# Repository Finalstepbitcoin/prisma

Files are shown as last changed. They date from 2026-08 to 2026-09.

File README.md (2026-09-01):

# Prisma — calcolatore offline

Un piccolo dispositivo **offline** che fa due cose sole:

1. **completa un seed BIP39** — gli dai le prime 11 (o 23) parole, lui calcola l'ultima
2. **costruisce una passphrase col metodo Diceware** — tu tiri i dadi, lui traduce i numeri in parole

Costa circa **20 euro** di componenti (aggiornato al 19 agosto 2026, a cui va aggiunto il case), non ha WiFi né Bluetooth, non salva niente
e il firmware è ispezionabile e riscrivibile da chiunque.

Canale YouTube: [Final Step Bitcoin](https://www.youtube.com/@final_step_bitcoin)

---

## Hai montato i pezzi. E adesso?

**Scarica un file solo e trascinalo.** Non serve installare niente sul
computer: ne' Python, ne' librerie, ne' le liste di parole.

1. prendi il file **`prisma-<versione>.uf2`** dall'ultima
   [release](https://github.com/Finalstepbitcoin/prisma/releases/latest);
2. tieni premuto **BOOTSEL** mentre colleghi il cavo micro-USB: compare un
   disco chiamato **RP2350**;
3. **trascina** il file su quel disco.

Il dispositivo riparte da solo e all'accensione mostra tre parole: devono
essere quelle scritte nella release.

**Se non ti fidi di quel file**, non usarlo: [costruiscitelo](#come-si-costruisce)
dal sorgente e verifica che venga identico, byte per byte. E' fatto apposta
perche' venga sempre lo stesso.

---

## Cosa serve

| Pezzo | Codice | Prezzo |
|---|---|---|
| Raspberry Pi Pico 2 con header | `RPI-PICO2-H` | ~7 € |
| Waveshare Pico-LCD-1.3 (240×240, joystick + 4 tasti) | `WS-19650` | ~9 € |
| Cavo micro-USB **dati** | `RPI-MUSB-1` | ~1,80 € |

**Attenzione a non prendere la versione "W"** del Pico: quella ha WiFi e Bluetooth,
e vanifica tutto il senso del progetto.

I due pezzi si incastrano. Il display va montato allineando il
simbolo USB stampato sul suo circuito con il connettore USB del Pico.

---

## Perché è fatto così

**Nessuna radio a bordo.** L'RP2350 non ha WiFi né Bluetooth: non è una scelta
del firmware, è il silicio che non li ha. È la garanzia più solida possibile.

**Non scrive nulla nella memoria permanente.** Le parole restano solo nella
memoria di lavoro e spariscono togliendo corrente. Questa scelta ha una
conseguenza importante: la memoria del dispositivo è **deterministica**, quindi
si può leggere e confrontare con quella di chiunque altro.

**Non genera entropia, la conserva.** Il caso lo porti tu — coi dadi, con una
moneta, come preferisci. Il dispositivo fa solo la traduzione, la stessa che
faresti a mano con le liste stampate, senza sbagliare riga.

**Non calcola chiavi private.** Niente derivazione, niente PBKDF2: il dispositivo
non può risalire al tuo portafoglio nemmeno per sbaglio.

**Il secure boot è deliberatamente disattivato.** Attivarlo impedirebbe
all'acquirente di riscrivere il firmware, cioè la garanzia più forte che questo
progetto possa offrire. È un pregio, non una mancanza.

---

## Come si costruisce

Serve Python 3 sul Mac o sul PC. Gli script usano solo la libreria standard,
tranne i due che impacchettano il file unico e disegnano il QR: quelli
vogliono una libreria ciascuno, installata in un ambiente isolato e con
l'impronta verificata (vedi `LEGGIMI-uf2.md`).

**Prima di tutto, MicroPython.** Non sta in questo repository, ed e' una
scelta: va preso dalla fonte, non dalle mani di chi ti vende il dispositivo.
Scarica da [micropython.org](https://micropython.org/download/RPI_PICO2/) la
versione per **Raspberry Pi Pico 2** e mettila nella cartella `firmware/`.

Quella usata qui e' `RPI_PICO2-20260406-v1.28.0.uf2`, SHA-256
`e65ad62a…b6ae`. Non e' un consiglio: gli script **rifiutano** qualunque
altro file, anche un `.uf2` di MicroPython legittimo ma di un'altra
versione. E' il motivo per cui due persone diverse, partendo dallo stesso
sorgente, ottengono un file finale **identico byte per byte**.

```bash
# 1. scarica dizionario e liste dalle fonti ufficiali, e disegna il QR
python3 prepara_wordlist.py
python3 prepara_diceware.py
.venv-strumenti/bin/python prepara_qr.py     # solo se cambia l'indirizzo

# 2. verifica che i calcoli siano corretti, PRIMA di toccare il dispositivo
python3 test_bip39.py
python3 test_diceware.py

# 3. impacchetta tutto in un file solo
.venv-strumenti/bin/python crea_uf2.py       # produce prisma-<versione>.uf2
.venv-strumenti/bin/python prova_uf2.py      # 12 controlli, senza dispositivo

# 4. annota le tre parole da pubblicare e stampare
python3 prepara_impronta.py
```

**Le liste di parole si scaricano dalle fonti originali** al momento della
compilazione, e ognuna resta sotto la propria licenza. In `liste-originali/`
c'e' anche una copia archiviata delle due liste Diceware, usata **solo** se il
download non riesce: serve a poter ricostruire il firmware anche se un domani
il sito di un autore non ci fosse piu', ed e' cio' che permette a chi riceve
un dispositivo gia' pronto di avere il sorgente corrispondente, come chiede la
licenza GPL della lista italiana. In tutti e due i casi gli script verificano
che la lista sia completa e ne confrontano l'impronta SHA-256 con quella
scritta nel codice: la copia archiviata e' una rete di sicurezza, non una
scorciatoia.

---

## Come si carica sul dispositivo

**Un file solo, e niente da installare sul computer.**

1. tieni premuto **BOOTSEL** mentre colleghi il cavo;
2. rilascia: compare un disco chiamato **RP2350**;
3. **trascina** `prisma-<versione>.uf2` su quel disco.

Il dispositivo si riavvia da solo dopo un paio di secondi e il disco
sparisce. Se il sistema avvisa che il disco non e' stato espulso
correttamente, e' normale: vuol dire che ha funzionato. All'accensione
devono comparire le tre parole dell'impronta.

**Su macOS il file va trascinato dal Finder, non copiato da terminale.**
`cp` scrive i settori in un ordine che il caricatore del Pico non accetta:
il file passa, il comando non da' errore, ma il dispositivo resta fermo in
BOOTSEL senza riavviarsi.

Dentro quel file c'e' **MicroPython intatto**, gli stessi byte che
distribuisce micropython.org, piu' un archivio con i file del programma.
Non e' una versione modificata: `prova_uf2.py` rilegge il file appena
prodotto e lo dimostra, blocco per blocco, prima che tu lo carichi.

### La strada lunga, per chi sviluppa

Chi lavora al codice e vuole cambiare un file alla volta senza rifare il
pacchetto ogni volta puo' ancora caricare MicroPython per conto suo e poi
copiare i file col terminale:

```bash
python3 installa.py     # copia tutti i file sul dispositivo in un colpo solo
```

Serve solo a questo. Per usare il dispositivo, o per darlo a qualcuno, la
strada e' il file unico qui sopra.

---

## I file

**Girano sul dispositivo**

| File | Cosa fa |
|---|---|
| `main.py` | tre righe: fa partire tutto all'accensione |
| `interfaccia.py` | menu, inserimento delle parole, schermate |
| `bip39_checksum.py` | il calcolo del checksum BIP39 |
| `impronta.py` | le tre parole mostrate all'accensione |
| `diceware.py` | dai numeri dei dadi alle parole |
| `schermo.py` | driver del display e lettura dei comandi |

**Girano sul computer**

| File | Cosa fa |
|---|---|
| `prepara_wordlist.py` | scarica e verifica il dizionario BIP39 |
| `prepara_diceware.py` | scarica e verifica le due liste Diceware |
| `test_bip39.py` | confronta i calcoli coi vettori ufficiali BIP39 |
| `test_diceware.py` | riconfronta le liste con le fonti, voce per voce |
| `prepara_qr.py` | disegna il QR del canale (unico script con una dipendenza) |
| `prepara_impronta.py` | calcola l'impronta attesa, da pubblicare e stampare |
| `crea_uf2.py` | impacchetta MicroPython e il programma in **un file solo** |
| `prova_uf2.py` | rilegge quel file e controlla che dentro ci sia il giusto |
| `installa.py` | la strada lunga: copia i file uno a uno, serve solo a chi sviluppa |
| `parla_col_pico.py` | parla col dispositivo senza installare programmi |
| `prova_percorsi.py` | ripercorre da solo tutte le strade dell'interfaccia |

---

## Come si verifica

I test scaricano i **vettori ufficiali BIP39** e controllano che il motore dia
esattamente i risultati previsti dallo standard — non "sembra funzionare", ma
*è dimostrato conforme*.

```
python3 test_bip39.py      →  186 controlli
python3 test_diceware.py   →   32 controlli
```

E sul dispositivo, una prova che ripercorre da sola ogni schermata e ogni
strada dell'interfaccia — inserimento parole, bit, dadi, ritorni indietro,
avvisi — controllando che nessuna finisca in errore:

```
python3 parla_col_pico.py copia prova_percorsi.py
python3 parla_col_pico.py esegui --pulito "import prova_percorsi"
                           →  18 percorsi
```

**Ricordati di togliere `prova_percorsi.py` dal dispositivo quando hai
finito**: e' un file in piu', quindi cambia l'impronta.

Fra questi ci sono due verifiche che vale la pena citare:

- la versione veloce del calcolo viene confrontata con una versione lenta e
  ovvia, tenuta nel codice apposta come metro di paragone
- per **tutte e 128** le posizioni possibili si verifica che i bit di entropia
  forniti dall'utente finiscano nella parola giusta

## L'impronta del firmware

All'accensione il dispositivo mostra **tre parole BIP39**. Sono i primi 33 bit
dello SHA-256 di tutto quello che esegue: la memoria del firmware piu' il
contenuto di **ogni file presente nel dispositivo** — tutti, non solo i `.py`,
comprese le sottocartelle. MicroPython infatti sa caricare anche i moduli gia'
compilati (`.mpy`) e cerca in `/lib`: misurare i soli `.py` avrebbe lasciato
uno spazio dove nascondere qualcosa.

```
python3 prepara_impronta.py
```

calcola lo stesso valore sul computer. Se le tre parole coincidono, dentro il
dispositivo c'e' esattamente quello che c'e' in questo repository.

Basta aggiungere un file perche' cambino — di qualunque tipo, anche dentro
una sottocartella: e' proprio quello che devono fare.

**Attenzione a cosa dimostra, e cosa NON dimostra**: e' il firmware stesso a
calcolare e mostrare queste tre parole. Un firmware malevolo mostrerebbe
comunque le parole giuste — sia che la manomissione sia avvenuta durante la
costruzione, sia durante il trasporto, in magazzino o presso un rivenditore:
in tutti questi casi chi manomette il dispositivo controlla lo stesso codice
che calcola l'impronta, e puo' farla tornare giusta a piacere.

Questo controllo serve solo contro il deterioramento accidentale della
memoria (un bit corrotto, un file mancante), **non contro una manomissione
voluta, di nessun tipo**. Per una prova vera serve leggere il contenuto da
SPENTI, con un canale che il firmware non controlla:

- `picotool save -a` / `picotool verify` da BOOTSEL, che risponde il
  bootloader in ROM col firmware fermo — vedi la guida
- oppure riscrivere tu stesso il firmware: invece di controllare quello che
  c'e' dentro, lo sostituisci con quello che scarichi tu

  **Attenzione al modo in cui si riscrive.** Il `.uf2` di MicroPython occupa
  i primi 320 KB della memoria, e il caricatore scrive SOLO i blocchi
  contenuti nel file: tutto quello che sta piu' in alto — compreso l'archivio
  dove vivono i dieci `.py` del programma — resta dov'era. Riscrivere
  MicroPython da solo quindi NON cancella i file gia' presenti. Per
  sostituire davvero tutto, la memoria va azzerata prima (`flash_nuke.uf2`
  di Raspberry Pi, oppure `picotool erase`).

---

## Comandi

| | |
|---|---|
| joystick | si muove fra lettere, voci di menu, elenchi |
| A | conferma, scegli |
| B | cancella, torna indietro |
| X e Y | i valori 1 e 0 quando si inseriscono i bit |

Nei tiri di dado: su = 1, destra = 2, giù = 3, sinistra = 4, centro = 5,
tasto X = 6. Lo schema è disegnato sullo schermo.

---

## Avvertenze

**Spegnere significa staccare il cavo, non premere RESET.** Il reset riavvia il
processore ma non azzera la memoria di lavoro.

**Una passphrase non ha checksum.** Se la trascrivi male non te ne accorgi: non
compare nessun errore, entri semplicemente in un altro portafoglio, vuoto. Il
seed BIP39 invece da questo ti protegge.

**Alimentalo da un caricatore da telefono**, non dal computer. Molte power bank
si spengono da sole quando l'assorbimento è basso come quello di questo
dispositivo.

**Questo progetto non è stato sottoposto ad audit professionali.** I calcoli sono
verificati contro i vettori ufficiali, il resto è codice scritto con cura ma non
revisionato da terzi. Trattalo di conseguenza.

---

## Licenze

Il codice di questo progetto è sotto licenza **MIT** (vedi `LICENSE`).

Le liste di parole restano di chi le ha fatte, ognuna con la propria licenza,
e sono archiviate in [`liste-originali/`](liste-originali/) insieme al testo
della GPL. Il firmware assemblato, contenendo la lista Diceware italiana, esce
sotto **GPL-3.0**. I dettagli sono in [`LICENZE-TERZI.md`](LICENZE-TERZI.md).

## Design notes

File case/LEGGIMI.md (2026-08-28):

# Custodia da stampare in 3D

**→ <https://makerworld.com/en/models/3230142-raspberry-pi-pico-2-case-waveshare-1-3-lcd>**

## Di chi è, e cosa puoi farci

| | |
|---|---|
| Disegno | **Zez0000** su MakerWorld |
| Basato su | il modello originale di **Tomáš Plass** ([Printables](https://www.printables.com/model/1322102-waveshare-pico-13-lcd-case)) |
| Licenza | **Creative Commons Attribuzione - Non commerciale (CC BY-NC)** |

Attenzione, la licenza della custodia **non è quella di Prisma**. Il firmware e tutto il resto del repository sono MIT, quindi liberi anche per usi commerciali; la custodia no: **CC BY-NC vuol dire che puoi stamparla per te, ma non venderla né vendere un dispositivo che la monta.** Se ti serve per qualcosa di commerciale, devi chiedere il permesso a chi l'ha disegnata.

## Come si stampa

Le impostazioni consigliate da chi l'ha disegnata:

- materiale **PLA**
- altezza strato **0,20 mm**
- **2 pareti**, riempimento **15%**
- circa **40 minuti** in tutto

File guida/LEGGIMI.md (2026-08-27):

# Guida d'uso — "Prisma, guida pratica"

Questa guida spiega l'utilizzo del dispositivo: come si accende, come si usano
le due modalità, come si verifica il firmware, cosa non bisogna fare. Viene
consegnata a chi acquista "Prisma" già assemblato.

## Il PDF

`PRISMA - GUIDA PRATICA.pdf` è il foglio pronto da stampare, fronte/retro
su un A4. È la stessa identica copia che finisce nella scatola: `build.sh`
la aggiorna qui in automatico ogni volta che rigenera il foglio, così le due
non possono divergere.

### Attenzione alle tre parole stampate sopra

Sulla prima facciata, nel riquadro arancione, ci sono **tre parole BIP39**:
sono l'impronta del firmware caricato sui dispositivi assemblati. Un
Prisma già montato deve mostrare esattamente quelle all'accensione.

**Se il firmware lo compili tu**, quelle tre parole non ti dicono niente sul
tuo dispositivo: calcola le tue con `python3 prepara_impronta.py` e confronta
con quelle che vedi sullo schermo. È il confronto che conta, non il valore
stampato qui.

A ogni cambio di firmware vengono aggiornate tutte e due le copie della
guida — quella di carta nella scatola e questo PDF — così le tre parole
restano quelle vere.

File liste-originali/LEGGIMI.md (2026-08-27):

# Le liste originali, archiviate qui

In questa cartella ci sono le **liste di parole Diceware così come sono state
scaricate** dalle pagine dei loro autori, senza nessuna modifica: sono i file
da cui `prepara_diceware.py` genera `diceware_en.py` e `diceware_it.py`, cioè
quello che poi finisce dentro il dispositivo.

## Perché stanno qui

Due motivi, tutti e due pratici.

**Perché il firmware sia ricostruibile anche fra dieci anni.** Se un giorno il
sito di un autore non c'è più, senza queste copie non sarebbe più possibile
rigenerare il firmware né controllare che quello installato corrisponda al
sorgente. La verifica del dispositivo si regge tutta su questa possibilità.

**Perché la licenza lo chiede.** Il firmware assemblato contiene la lista
italiana, che è GPL-3.0. Chi riceve un dispositivo già pronto deve poter
ottenere il sorgente corrispondente: adesso è qui, insieme al codice.

Attenzione, le copie **non sostituiscono la verifica**: `prepara_diceware.py`
scarica sempre dalla fonte originale e usa questi file solo se il download non
riesce. In tutti e due i casi confronta lo SHA-256 con quello scritto nel
codice, e si ferma se non corrisponde. La copia archiviata è una rete di
sicurezza, non una scorciatoia.

## Cosa c'è

### `diceware-inglese-reinhold.asc`

| | |
|---|---|
| Autore | Arnold Reinhold, che il metodo Diceware l'ha inventato nel 1995 |
| Licenza | **CC-BY 4.0** — uso commerciale permesso, serve l'attribuzione |
| Pagina | <https://theworld.com/~reinhold/diceware.html> |
| File | <https://theworld.com/~reinhold/diceware.wordlist.asc> |
| SHA-256 | `3cd6164a99e95381f8620aec782a933545bcd5833fa331d267a6829f6665256e` |
| Voci | 7776 |

Reinhold concede la lista inglese sotto CC-BY 4.0. Il *testo della sua pagina*
è invece CC-BY-NC-ND, cioè non commerciale: è una distinzione da non
confondere, qui si usa la lista.

### `diceware-italiana-gamberini-v4.txt`

| | |
|---|---|
| Autore | Tarin Gamberini |
| Licenza | **GPL-3.0-or-later** (testo completo in `COPYING-GPL-3.0.txt`) |
| Pagina | <https://www.taringamberini.com/it/diceware_it_IT/lista-di-parole-diceware-in-italiano/> |
| File | versione 4, `word_list_diceware_it-IT-4.txt` |
| SHA-256 | `b441559b64fb7041b9bbcecb3c43111f2523ec84e172670409f40c462eda0b93` |
| Voci | 7776 |

Non è la traduzione di quella inglese: è una lista a sé, e lo stesso tiro di
dadi dà una parola diversa nelle due liste.

### `COPYING-GPL-3.0.txt`

Il testo completo della licenza GPL-3.0, scaricato da
<https://www.gnu.org/licenses/gpl-3.0.txt>. Vale per la lista italiana e per
il firmware che la contiene.

## Cosa NON cambia

Il codice di questo progetto resta sotto licenza **MIT** (vedi `LICENSE`).
I file di questa cartella non sono nostri e restano di chi li ha fatti, ognuno
con la propria licenza. Il firmware assemblato, contenendo la lista italiana,
esce sotto **GPL-3.0**: è scritto in `LICENZE-TERZI.md`.

Il dizionario BIP39 inglese non sta qui: fa parte della specifica pubblica di
Bitcoin e si scarica dal repository ufficiale dei BIP, che non è il sito
personale di nessuno.

## Se una lista viene aggiornata dall'autore

Non basta sostituire il file. La procedura è:

1. scaricare la nuova versione e **guardarla**, confrontandola con la vecchia;
2. aggiornare `impronta_attesa` dentro `prepara_diceware.py`;
3. sostituire il file in questa cartella e aggiornare lo SHA-256 qui sopra;
4. rilanciare `prepara_diceware.py`, `test_diceware.py` e `crea_uf2.py`;
5. rifare la guida con `guida/build.sh`: cambiando la lista cambia il
   firmware, e quindi cambiano le tre parole dell'impronta stampate sul
   foglio. `build.sh` da solo si rifiuta di stampare se non le si aggiorna.

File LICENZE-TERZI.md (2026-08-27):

# Licenze e attribuzioni

Questo progetto usa liste di parole e idee di altre persone. Qui c'è scritto
di chi sono e a quali condizioni si possono usare.

Gli script `prepara_wordlist.py` e `prepara_diceware.py` scaricano le liste
dalle fonti originali al momento della compilazione. Delle due liste Diceware
c'è anche una **copia archiviata** in [`liste-originali/`](liste-originali/),
usata solo se il download non riesce: senza, il giorno in cui il sito di un
autore sparisse non sarebbe più possibile ricostruire il firmware né darne il
sorgente a chi ha comprato un dispositivo, come invece la GPL richiede.

Il codice di questo progetto resta sotto licenza MIT. I file archiviati non
sono nostri: ognuno resta sotto la licenza del proprio autore, indicata qui
sotto e ripetuta nel `LEGGIMI.md` di quella cartella.

---

## Dizionario BIP39 (inglese, 2048 parole)

- **Fonte**: [repository ufficiale dei BIP](https://github.com/bitcoin/bips/blob/master/bip-0039/english.txt)
- **Standard**: [BIP-39](https://github.com/bitcoin/bips/blob/master/bip-0039.mediawiki)
- Fa parte della specifica pubblica di Bitcoin.

## Lista Diceware inglese (7776 voci)

- **Autore**: Arnold Reinhold, che il metodo Diceware l'ha inventato nel 1995
- **Licenza**: **CC-BY 4.0** — uso commerciale permesso, serve l'attribuzione
- **Pagina**: <https://theworld.com/~reinhold/diceware.html>
- **Copia archiviata**: `liste-originali/diceware-inglese-reinhold.asc`

Sulla sua pagina Reinhold scrive che concede i diritti sulla lista inglese
sotto CC-BY 4.0. Attenzione a non confondersi: il *testo della pagina* è invece
CC-BY-NC-ND, cioè non commerciale. È la lista che ci interessa, ed è quella
permissiva.

## Lista Diceware italiana (7776 voci)

- **Autore**: Tarin Gamberini
- **Licenza**: **GPL-3.0-or-later** per la versione testuale (testo completo
  della licenza in `liste-originali/COPYING-GPL-3.0.txt`)
- **Pagina**: <https://www.taringamberini.com/it/diceware_it_IT/lista-di-parole-diceware-in-italiano/>
- **Copia archiviata**: `liste-originali/diceware-italiana-gamberini-v4.txt`

Non è la traduzione di quella inglese: è una lista a sé, e lo stesso numero di
dadi dà una parola diversa nelle due liste.

## Motore dei calcoli

La logica del checksum BIP39 deriva da **[embit](https://github.com/diybitcoinhardware/embit)**
(licenza MIT), una libreria Bitcoin pensata per i sistemi embedded. È la stessa
libreria usata sia da [SeedSigner](https://github.com/SeedSigner/seedsigner) sia
da [Krux](https://github.com/selfcustody/krux).

I vettori di test provengono da
**[trezor/python-mnemonic](https://github.com/trezor/python-mnemonic)**, l'implementazione
di riferimento dello standard.

## MicroPython

Il dispositivo esegue [MicroPython](https://micropython.org/) (licenza MIT).

---

## Le due librerie usate per costruire

Non finiscono dentro il dispositivo: servono sul computer, al momento di
preparare i file. Le citiamo lo stesso, perche' chi ricostruisce il progetto
le scarica.

- **littlefs-python** (BSD-3-Clause), di Jurg Rast — impacchetta i file del
  programma nell'archivio del `.uf2`. E' un involucro attorno alla libreria C
  littlefs, la stessa che gira dentro MicroPython.
  <https://github.com/jrast/littlefs-python>
- **segno** (BSD-3-Clause) — disegna i codici QR stampati sulla guida.
  <https://github.com/heuer/segno>

## Cosa significa in pratica

**Il codice di questo repository è MIT**: chiunque può prenderlo e farne quello
che vuole, anche a scopo commerciale, mantenendo l'avviso di copyright.

**Un firmware assemblato che includa la lista italiana esce sotto GPL-3.0**,
perché quella lista è GPL. In pratica questo obbliga chi lo distribuisce a
fornire i sorgenti e a permettere all'acquirente di installare una versione
modificata — cioè esattamente quello che questo progetto promette comunque.

Un firmware con la sola lista inglese non ha questo vincolo: MIT e CC-BY
bastano.

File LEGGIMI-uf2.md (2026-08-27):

# Il file unico — note di lavoro

Serve a produrre **un solo file** da trascinare sul dispositivo, al posto
di "carica MicroPython, poi copia dieci file col terminale".

Nato sul ramo `uf2-unico`, portato qui il 27 agosto 2026 dopo la prima
prova su hardware vero.

## Cosa c'è di nuovo

| File | Cosa fa |
|---|---|
| `crea_uf2.py` | costruisce `prisma-<versione>.uf2` |
| `prova_uf2.py` | rilegge il file prodotto e controlla che dentro ci sia il giusto |

Non è stata toccata **nessuna riga** del programma che gira sul dispositivo:
cambia solo il modo in cui i file ci arrivano dentro.

## Come si usa

```bash
.venv-strumenti/bin/python crea_uf2.py     # produce prisma-1.0.uf2
.venv-strumenti/bin/python prova_uf2.py    # 12 controlli, senza dispositivo
```

## La libreria in più

`crea_uf2.py` è l'unico pezzo del progetto che ha bisogno di
**littlefs-python** (BSD-3-Clause, involucro attorno alla libreria C
littlefs 2.11.2 — la stessa che gira dentro MicroPython sul dispositivo).

Va installata **solo nell'ambiente isolato**, mai nel Python di sistema, e
sempre verificando l'impronta del pacchetto. I comandi qui sotto sono per
**Mac con chip Apple**: su un altro sistema cambia il nome del pacchetto, e
con esso l'impronta da confrontare — quella giusta si prende dalla pagina
del progetto su PyPI.

```bash
python3 -m venv .venv-strumenti
curl -o littlefs_python-0.19.0-cp314-cp314-macosx_11_0_arm64.whl \
  https://files.pythonhosted.org/packages/26/12/ab923553e4894fbf44f4692d6c5898c1e66f41e57ff7a73b90e8aa0fb6f5/littlefs_python-0.19.0-cp314-cp314-macosx_11_0_arm64.whl
shasum -a 256 littlefs_python-0.19.0-cp314-cp314-macosx_11_0_arm64.whl
#  deve dare: d054ac280541afdae5722fb8d7ebc0e121d822c33d95d57889fd8fab2a211486
.venv-strumenti/bin/pip install --no-index --no-deps littlefs_python-*.whl
```

Non serve né a chi compra il dispositivo né a chi vuole solo verificare i
calcoli: quelli restano due comandi con la sola libreria standard di Python.

## I parametri dell'archivio: da dove vengono

Non sono stati indovinati. Vengono dalla sorgente ufficiale di MicroPython e
devono combaciare **esattamente**, altrimenti il dispositivo si accende e non
trova niente:

| Valore | Da dove | Quanto |
|---|---|---|
| dimensione archivio | `ports/rp2/boards/RPI_PICO2/mpconfigboard.cmake` | 3.145.728 byte (3 MB) |
| inizio archivio | `ports/rp2/rp2_flash.c` (4 MB − 3 MB) | 1 MB, cioè `0x10100000` |
| blocco | `ports/rp2/rp2_flash.c`, `FLASH_SECTOR_SIZE` | 4096 byte |
| scrittura | `ports/rp2/modules/_boot.py`, `VfsLfs2(bdev, progsize=256)` | 256 byte |

Il firmware finisce a 320 KB, l'archivio comincia a 1024 KB: in mezzo restano
i dati di collaudo che il Raspberry Pi scrive in fabbrica a 508 KB, che non
vengono né scritti né misurati.

## Due cose che è importante sapere

**L'immagine è sempre identica a parità di file.** Ricostruita tre volte di
fila dà lo stesso SHA-256: chiunque può rifare il file e ottenere il nostro,
byte per byte. Senza questa proprietà l'intera storia della verifica non
starebbe in piedi.

**Le tre parole dell'impronta non cambiano.** L'impronta misura MicroPython
(che resta intatto) e i dieci file (che sono gli stessi): un dispositivo
caricato col file unico è indistinguibile da uno installato col metodo
vecchio. `prova_uf2.py` lo verifica.

## Perché il file è da 1 MB e non da 6

littlefs sparge i file in giro per l'archivio invece di metterli in fila —
lo fa apposta, per non consumare sempre le stesse celle. Scrivendo tutto il
tratto dal primo all'ultimo blocco usato ci porteremmo dietro 2,4 MB di
vuoto. Siccome ogni blocco `.uf2` si porta dietro il proprio indirizzo, si
scrivono solo i blocchi che contengono qualcosa.

È sicuro anche rispetto a un'installazione precedente: il caricatore del Pico
cancella l'intero settore da 4096 byte prima di scriverne anche un pezzo, e
l'elenco dei file (i primi due blocchi) viene riscritto per intero, quindi
niente di vecchio resta raggiungibile.

## La prova sull'hardware: fatta il 27 agosto 2026

Caricato su un Pico 2 vero: il disco si smonta da solo, il dispositivo
riparte e mostra `Prisma 1.0` con le tre parole dell'impronta.

**La prima prova ha bocciato il file**, ed e' servita esattamente a questo.
Il dispositivo restava fermo in BOOTSEL: il file veniva scritto per intero,
nessun errore da nessuna parte, ma niente riavvio. Il motivo era la
numerazione dei blocchi, che il caricatore conta **per famiglia** e non su
tutto il file (il dettaglio sta nel commento dentro `crea_uf2.py`). I dodici
controlli passavano lo stesso, perche' due di essi pretendevano proprio la
regola sbagliata: sono stati riscritti.

Se un domani qualcosa non andasse, il sintomo dice dove guardare:

- **il disco resta montato e non riparte** → la numerazione dei blocchi
- **si accende ma resta muto** → i parametri dell'archivio non combaciano
- **riparte in modo continuo** → problema nel firmware, non nell'archivio
- **tre parole diverse da quelle attese** → nell'archivio e' finito qualcosa
  in piu' o in meno

**Su macOS il file va trascinato dal Finder**, non copiato da terminale:
`cp` scrive i settori in un ordine che il caricatore non accetta, non da'
errore, e il dispositivo resta fermo senza che nulla lo segnali.

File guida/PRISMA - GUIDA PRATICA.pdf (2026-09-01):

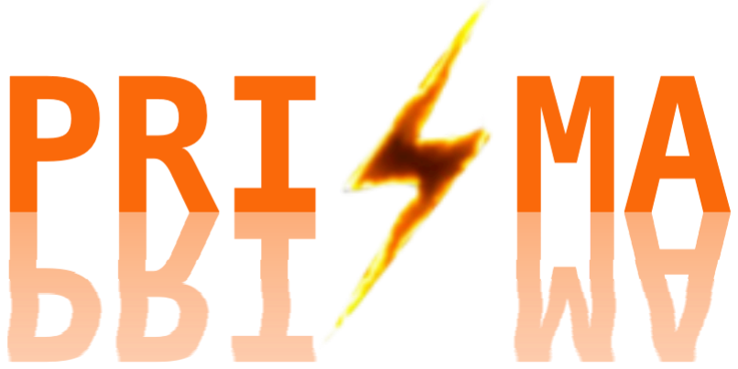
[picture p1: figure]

# GUIDA PRATICA

DISPOSITIVO OFFLINE · ULTIMA PAROLA BIP39 E PASSPHRASE DICEWARE

## 1 COSA FA E COSA NON FA

M O D A L I T À 1

### CHECKSUM

Gli dai le prime 11 parole del seed (o
le prime 23) e lui calcola l’ultima valida.

M O D A L I T À 2

### PASSPHRASE

Tu tiri i dadi, lui li traduce in parole della lista Diceware. Il caso lo porti tu.

Q U E L L O C H E N O N F A
Niente WiFi né Bluetooth: non è una scelta del programma, è il chip che non li ha. Non salva niente e non calcola chiavi private: non può risalire al tuo portafoglio.

## 2 ACCENDILO E CONTROLLA L’IMPRONTA

Collegalo con un cavo micro-USB a un caricatore da telefono, non al computer: molte power bank potrebbero non funzionare perché il dispositivo assorbe pochissimo. Per una maggiore sicurezza puoi aggiungere un Data Blocker USB. Non c’è niente da installare, parte da solo. Ma se non ti fidi, puoi scaricare il firmware da github.com/Finalstepbitcoin/prisma e installarlo in autonomia.

ALL’ACCENSIONE DEVE MOSTRARE
STABLE CHAIR PROBLEM

Sono l’impronta di tutto quello che il dispositivo esegue. Se ne mostra tre diverse, dentro c’è qualcosa di diverso: fermati e riscrivi il firmware.
Protegge solo da un guasto accidentale, non da una manomissione voluta: un firmware manomesso potrebbe mostrarle comunque giuste. Verifica vera al punto 6.

Confrontale con quelle pubblicate su Nostr da questa chiave: npub17ugguepv89nvdrd72j7j25ymuts6w3d3lnsg6f0xgm2ah8zskhqq3v5ulj

## 3 I COMANDI

joystick | si muove fra lettere, voci di menu ed elenchi | B | cancella; a casella vuota torna indietro
A | conferma, sceglie | X e Y | i valori 1 e 0 quando si inseriscono i bit

Nei tiri di
dado:
su = 1 | destra = 2 | giù = 3 | sinistra = 4 | centro = 5 | X = 6

— lo schema è disegnato sullo schermo.

## 4 MODALITÀ CHECKSUM: L’ULTIMA PAROLA DEL SEED

Un errore nell’inserimento delle parole darebbe un checksum corretto, ma su parole sbagliate. Il dispositivo ti mostrerà le parole che hai inserito. Controllale prima di proseguire. Una volta terminato, non fotografare lo schermo per salvare la parola.
1 Menu → Checksum. Scegli se il tuo seed è da 12 o da 24 parole.

2

Inserisci le prime 11 parole (o 23). Per ogni parola compare la griglia delle sole lettere ancora possibili: il joystick si muove, A conferma. Quando restano cinque parole o meno te le mostra e scegli quella giusta.
B cancella una lettera; a casella vuota, torna alla parola precedente.

3 Aspetta il calcolo. Con 11 parole ci mette circa 3 secondi e mezzo, con 23 circa 6: la barra arancione mostra a che punto

### 4 Scegli come completare. Il dispositivo propone tre strade:

Bit rimasti — quella giusta: inserisci i 7 bit che ti avanzano dai dadi (3 se il seed è da 24), nell’ordine in cui li hai generati. X vale 1,

Scegli tu — se non ti avanzano bit di entropia puoi sceglierne una a caso (NON consigliato): scorri l’elenco, X filtra per iniziale. Tutti zeri — butta via i bit che avanzano. Solo se sai perché lo stai facendo.

5 Copia la parola che compare grande, in verde, e rileggila confrontandola con lo schermo.
6 Stacca il cavo. L’ultima schermata è un vicolo cieco voluto: nessun tasto porta da nessuna parte. È l’unico modo di azzerare davvero la memoria di lavoro.

PRISMA · GUIDA PRATICA | FACCIATA 2 DI 2

## 5 MODALITÀ PASSPHRASE: I DADI E LA LISTA DICEWARE

1 Menu → Passphrase. Scegli la lista: Inglese (Reinhold) o Italiano (Gamberini). Sono 7.776 voci ciascuna e non sono la traduzione l’una dell’altra: sono due liste indipendenti.
2 Tira cinque dadi per ogni parola e registra i valori col joystick. Cinque dadi fanno 6×6×6×6×6 = 7.776 combinazioni: una per ogni voce, nessuno scarto.
Se un lancio non ti piace, tienilo lo stesso. Ritirarlo rimette la tua testa nel processo e distrugge la casualità.
3 Guarda i bit che stai accumulando. Dopo ogni parola: A per farne un’altra, Y per fermarti. Sotto le 6 parole il dispositivo ti avvisa ogni volta; il massimo è 20 (258,5 bit), in due schermate da dieci.
4 Se compare “copiala esatta!” la voce contiene simboli o cifre — per esempio a, @, i’ve, 12. Sono legittime e vanno copiate esattamente così.
5 Copia tutte e due le schermate finali — prima l’elenco numerato, poi la passphrase per intero — sullo stesso foglio. Poi stacca il cavo.
Con più di 10 parole l’elenco numerato sta su due schermate, con una freccia per passare alla seconda: copiale entrambe.

U N A P A S S P H R A S E N O N H A
C H E C K S U M
Se la trascrivi male non ricevi nessun
errore: entri semplicemente in un altro portafoglio, vuoto. Il seed BIP39 da questo ti protegge, la passphrase no.

C O M E S C R I V E R E L A
P A S S P H R A S E
rune a @ issue cat orin è la stringa da digitare, spazi compresi. Senza spazio, due parole potrebbero confondersi. Se vuoi scrivere la passphrase senza gli spazi, assicurati di conservare l’elenco delle parole.

C O M E S A L V A R E L A
P A S S P H R A S E
Viene mostrato sia l’elenco delle singole parole, sia la stringa intera, per una doppia conferma. Salvali entrambi. Annota anche come scriverai la passphrase (con/senza spazi). Non fotografare mai lo schermo.

## 6 COME VERIFICARE IL FIRMWARE

LIVELLO 1 Le tre parole all’accensione. Immediato, ma è il programma che parla di sé: rileva un guasto accidentale, non una manomissione voluta.

LIVELLO 2 Riscrivilo tu. È il percorso più sicuro: invece di controllare quello che c’è dentro, lo sostituisci con quello che scarichi tu. Inquadra il codice QR o vai su github.com/Finalstepbitcoin/prisma e segui le istruzioni.

LIVELLO 3 Leggilo e confrontalo. Sempre da BOOTSEL, un programma di verifica rilegge la memoria a dispositivo spento: risponde il bootloader di fabbrica, non il firmware. È l’unica verifica che il firmware non può falsificare.

CODICE GITHUB

## 7 AVVERTENZE

S P E G N E R E = S T A C C A R E I L
C A V O
Il tasto RESET riavvia il processore ma non azzera la memoria di lavoro. L’unico spegnimento vero è togliere la corrente.

U N A M O D A L I T À P E R S E S S I O N E
Usa checksum e passphrase in due sessioni separate, staccando il cavo in mezzo: così il dispositivo non ha mai in memoria tutte e due le metà del tuo segreto.

T R A S C R I V I I L R I S U L T A T O
Trascrivi il segreto (ultima parola o passphrase). Attenzione al foglio su cui scrivi perché contiene il tuo segreto in chiaro: conservalo o distruggilo dopo aver copiato i segreti su un supporto metallico.

Progetto libero e ispezionabile. Dizionario BIP39 dal repository ufficiale dei BIP · lista Diceware inglese di Arnold Reinhold (CC BY 4.0) · lista Diceware italiana di Tarin Gamberini (GPL-3.0-or-later) · motore dei calcoli derivato da embit (MIT), la stessa libreria usata da SeedSigner e Krux. Il codice del progetto è MIT; il firmware assemblato, contenendo la lista italiana, esce sotto GPL-3.0. Questo progetto non è stato sottoposto ad audit professionali: i calcoli sono verificati contro i vettori ufficiali BIP39, il resto è codice scritto con cura ma non revisionato da terzi. Trattalo di conseguenza.

FINAL STEP BITCOIN
YOUTUBE.COM/@FINAL_STEP_BITCOIN WWW.FINALSTEPBITCOIN.COM

Trovi anche una video guida sul mio canale YouTube

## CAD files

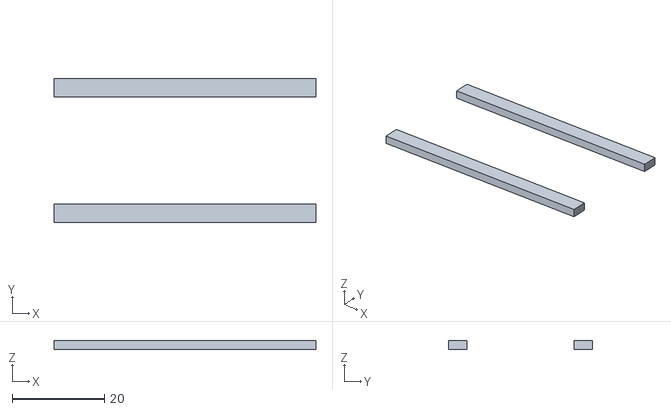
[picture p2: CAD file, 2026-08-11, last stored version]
case/cornice.stl
56.8 x 31.3 x 2.00

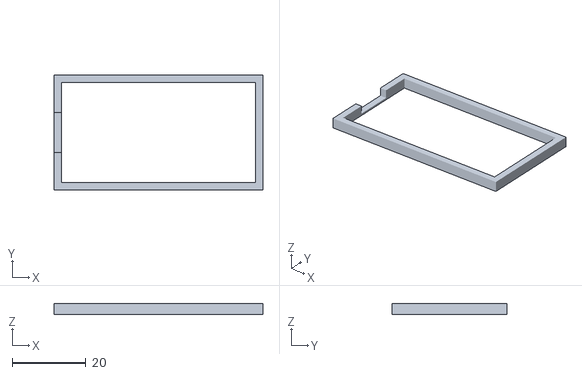
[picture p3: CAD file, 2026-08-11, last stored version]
case/prova_incastro.stl
56.8 x 31.3 x 3.00

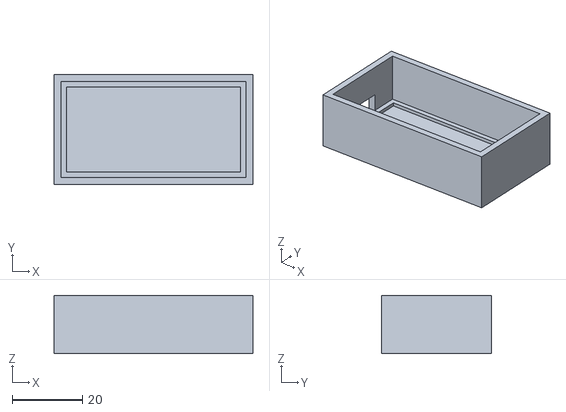
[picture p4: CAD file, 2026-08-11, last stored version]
case/vassoio.stl
56.8 x 31.3 x 16.6

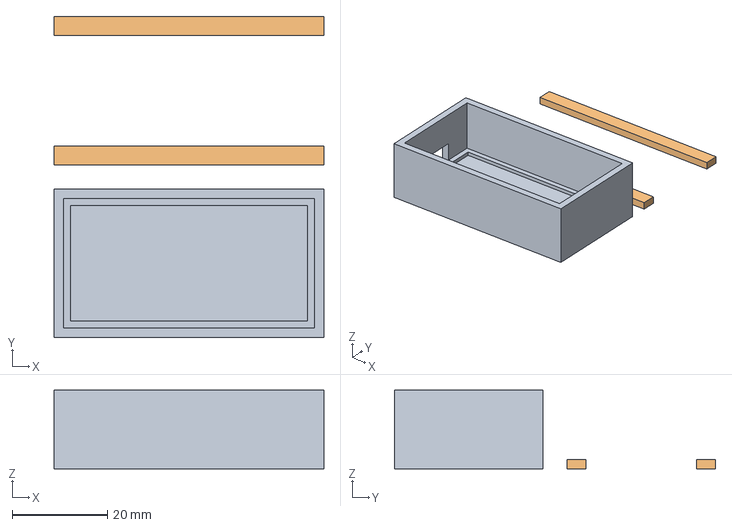
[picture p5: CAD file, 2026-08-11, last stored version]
case/custodia_completa.3mf
56.8 x 67.6 x 16.6 mm
vassoio
cornice

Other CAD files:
case/custodia_completa.stl

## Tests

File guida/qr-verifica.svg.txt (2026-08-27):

<svg class="qr" viewBox="-2 -2 33 33" xmlns="http://www.w3.org/2000/svg" shape-rendering="crispEdges"><rect x="-2" y="-2" width="33" height="33" fill="#fff"/><path fill="#000" d="M0 0h7v1h-7zM8 0h1v1h-1zM11 0h3v1h-3zM17 0h2v1h-2zM22 0h7v1h-7zM0 1h1v1h-1zM6 1h1v1h-1zM8 1h1v1h-1zM10 1h2v1h-2zM13 1h2v1h-2zM16 1h1v1h-1zM18 1h3v1h-3zM22 1h1v1h-1zM28 1h1v1h-1zM0 2h1v1h-1zM2 2h3v1h-3zM6 2h1v1h-1zM8 2h1v1h-1zM11 2h3v1h-3zM20 2h1v1h-1zM22 2h1v1h-1zM24 2h3v1h-3zM28 2h1v1h-1zM0 3h1v1h-1zM2 3h3v1h-3zM6 3h1v1h-1zM11 3h1v1h-1zM13 3h1v1h-1zM15 3h3v1h-3zM19 3h2v1h-2zM22 3h1v1h-1zM24 3h3v1h-3zM28 3h1v1h-1zM0 4h1v1h-1zM2 4h3v1h-3zM6 4h1v1h-1zM8 4h2v1h-2zM18 4h2v1h-2zM22 4h1v1h-1zM24 4h3v1h-3zM28 4h1v1h-1zM0 5h1v1h-1zM6 5h1v1h-1zM10 5h1v1h-1zM13 5h1v1h-1zM16 5h2v1h-2zM20 5h1v1h-1zM22 5h1v1h-1zM28 5h1v1h-1zM0 6h7v1h-7zM8 6h1v1h-1zM10 6h1v1h-1zM12 6h1v1h-1zM14 6h1v1h-1zM16 6h1v1h-1zM18 6h1v1h-1zM20 6h1v1h-1zM22 6h7v1h-7zM9 7h1v1h-1zM11 7h1v1h-1zM13 7h4v1h-4zM18 7h3v1h-3zM0 8h1v1h-1zM3 8h7v1h-7zM11 8h2v1h-2zM14 8h1v1h-1zM16 8h2v1h-2zM21 8h1v1h-1zM24 8h1v1h-1zM26 8h3v1h-3zM0 9h1v1h-1zM2 9h1v1h-1zM5 9h1v1h-1zM7 9h1v1h-1zM13 9h3v1h-3zM19 9h1v1h-1zM21 9h1v1h-1zM23 9h2v1h-2zM26 9h2v1h-2zM0 10h1v1h-1zM4 10h1v1h-1zM6 10h2v1h-2zM9 10h3v1h-3zM14 10h3v1h-3zM18 10h1v1h-1zM20 10h1v1h-1zM23 10h2v1h-2zM26 10h1v1h-1zM0 11h1v1h-1zM2 11h1v1h-1zM4 11h2v1h-2zM9 11h2v1h-2zM14 11h1v1h-1zM16 11h2v1h-2zM19 11h5v1h-5zM25 11h1v1h-1zM28 11h1v1h-1zM2 12h1v1h-1zM5 12h2v1h-2zM9 12h1v1h-1zM11 12h2v1h-2zM16 12h1v1h-1zM19 12h2v1h-2zM22 12h2v1h-2zM28 12h1v1h-1zM0 13h3v1h-3zM4 13h1v1h-1zM9 13h1v1h-1zM11 13h1v1h-1zM13 13h1v1h-1zM15 13h2v1h-2zM19 13h1v1h-1zM22 13h7v1h-7zM0 14h4v1h-4zM5 14h3v1h-3zM12 14h1v1h-1zM15 14h1v1h-1zM19 14h4v1h-4zM24 14h1v1h-1zM26 14h1v1h-1zM28 14h1v1h-1zM4 15h1v1h-1zM9 15h1v1h-1zM15 15h1v1h-1zM18 15h2v1h-2zM23 15h2v1h-2zM26 15h1v1h-1zM28 15h1v1h-1zM3 16h5v1h-5zM11 16h3v1h-3zM19 16h3v1h-3zM25 16h1v1h-1zM0 17h1v1h-1zM4 17h1v1h-1zM8 17h1v1h-1zM10 17h4v1h-4zM15 17h1v1h-1zM17 17h3v1h-3zM24 17h1v1h-1zM26 17h2v1h-2zM0 18h2v1h-2zM3 18h4v1h-4zM9 18h2v1h-2zM12 18h2v1h-2zM15 18h1v1h-1zM17 18h1v1h-1zM19 18h1v1h-1zM24 18h2v1h-2zM28 18h1v1h-1zM0 19h2v1h-2zM5 19h1v1h-1zM10 19h4v1h-4zM15 19h1v1h-1zM19 19h1v1h-1zM22 19h1v1h-1zM25 19h2v1h-2zM0 20h2v1h-2zM3 20h2v1h-2zM6 20h1v1h-1zM8 20h2v1h-2zM12 20h1v1h-1zM14 20h4v1h-4zM20 20h8v1h-8zM8 21h1v1h-1zM10 21h2v1h-2zM14 21h2v1h-2zM20 21h1v1h-1zM24 21h2v1h-2zM0 22h7v1h-7zM8 22h2v1h-2zM11 22h1v1h-1zM14 22h2v1h-2zM17 22h4v1h-4zM22 22h1v1h-1zM24 22h2v1h-2zM0 23h1v1h-1zM6 23h1v1h-1zM8 23h1v1h-1zM10 23h1v1h-1zM12 23h1v1h-1zM14 23h1v1h-1zM17 23h4v1h-4zM24 23h1v1h-1zM0 24h1v1h-1zM2 24h3v1h-3zM6 24h1v1h-1zM8 24h8v1h-8zM19 24h7v1h-7zM27 24h1v1h-1zM0 25h1v1h-1zM2 25h3v1h-3zM6 25h1v1h-1zM8 25h1v1h-1zM10 25h1v1h-1zM14 25h3v1h-3zM18 25h1v1h-1zM21 25h1v1h-1zM28 25h1v1h-1zM0 26h1v1h-1zM2 26h3v1h-3zM6 26h1v1h-1zM9 26h1v1h-1zM12 26h1v1h-1zM14 26h2v1h-2zM17 26h2v1h-2zM20 26h2v1h-2zM23 26h2v1h-2zM26 26h3v1h-3zM0 27h1v1h-1zM6 27h1v1h-1zM9 27h1v1h-1zM12 27h1v1h-1zM16 27h1v1h-1zM18 27h1v1h-1zM22 27h2v1h-2zM25 27h2v1h-2zM28 27h1v1h-1zM0 28h7v1h-7zM8 28h5v1h-5zM14 28h1v1h-1zM19 28h2v1h-2zM22 28h1v1h-1zM24 28h1v1h-1z"/></svg>

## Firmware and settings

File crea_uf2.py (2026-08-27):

#!/usr/bin/env python3
"""
crea_uf2.py  --  Final Step Bitcoin / Prisma

Costruisce UN SOLO file da trascinare sul dispositivo, che contiene sia
MicroPython sia il programma.

GIRA SUL MAC. Serve la libreria littlefs-python nell'ambiente isolato
.venv-strumenti (vedi LEGGIMI-uf2.md).

Uso:
    .venv-strumenti/bin/python crea_uf2.py

PERCHE' ESISTE
Fino a ieri chi voleva installarsi il software da solo doveva: azzerare la
memoria, caricare MicroPython, installare Python sul computer, aprire il
terminale e lanciare tre script che copiano dieci file uno per uno.
Con questo file: tiene premuto BOOTSEL, collega il cavo, trascina un file.
Trenta secondi, nessun programma da installare.

COME E' FATTO UN FILE .uf2
Non e' un formato misterioso: e' un elenco di blocchi da 512 byte, ognuno
dei quali dice "scrivi questi 256 byte a questo indirizzo". Il caricatore
del Pico li scrive uno per uno. Noi ne mettiamo insieme due gruppi:

    0x10000000  MicroPython           (320 KB, presi dal .uf2 ufficiale)
    0x10100000  l'archivio coi file   (costruito qui sul Mac)

I due gruppi non si toccano: il firmware finisce a 320 KB, l'archivio
comincia a 1024 KB. In mezzo, a 508 KB, ci sono i dati di collaudo che il
Raspberry Pi scrive in fabbrica: non li tocchiamo ne' li misuriamo (e' la
stessa ragione per cui l'impronta si ferma a 448 KB).

I PARAMETRI DELL'ARCHIVIO NON SONO INVENTATI
Vengono dalla sorgente di MicroPython, e devono combaciare ESATTAMENTE,
altrimenti il dispositivo si accende e non trova niente:

  ports/rp2/boards/RPI_PICO2/mpconfigboard.cmake
      MICROPY_HW_FLASH_STORAGE_BYTES 3145728        -> 3 MB di archivio
  ports/rp2/rp2_flash.c
      MICROPY_HW_FLASH_STORAGE_BASE (PICO_FLASH_SIZE_BYTES - STORAGE_BYTES)
                                                    -> comincia a 4MB-3MB = 1MB
      BLOCK_SIZE_BYTES (FLASH_SECTOR_SIZE)          -> blocchi da 4096 byte
  ports/rp2/modules/_boot.py
      vfs.VfsLfs2(bdev, progsize=256)               -> scritture da 256 byte
"""

import hashlib
import os
import re
import struct
import sys

# --- i valori presi dalla sorgente di MicroPython (vedi sopra) -------------
INIZIO_FLASH = 0x10000000
ARCHIVIO_INIZIO = 1024 * 1024          # 1 MB dall'inizio della memoria
ARCHIVIO_BYTE = 3145728                # 3 MB
BLOCCO = 4096
SCRITTURA = 256                        # progsize
LETTURA = 32                           # readsize, il valore predefinito

# --- il formato .uf2 -------------------------------------------------------
UF2_MAGIC0 = 0x0A324655
UF2_MAGIC1 = 0x9E5D5157
UF2_MAGIC_FINE = 0x0AB16F30
UF2_FLAG_FAMIGLIA = 0x00002000
CARICO = 256                           # byte utili per blocco

# --- cosa va dentro --------------------------------------------------------
# La stessa lista di installa.py e prepara_impronta.py.
FILE_DISPOSITIVO = (
    "bip39_checksum.py",
    "diceware.py",
    "diceware_en.py",
    "diceware_it.py",
    "impronta.py",
    "interfaccia.py",
    "main.py",
    "qr_canale.py",
    "schermo.py",
    "wordlist.py",
)

# La versione NON si scrive qui: si legge da interfaccia.py, che e' quella
# che il dispositivo mostra sullo schermo. Tenendone due copie, prima o poi
# il nome del file e la scritta sullo schermo direbbero numeri diversi.
VERSIONE = re.search(r'VERSIONE\s*=\s*"([^"]+)"',
                     open("interfaccia.py").read()).group(1)


# ---------------------------------------------------------------------------
# 1. l'archivio
# ---------------------------------------------------------------------------

def costruisci_archivio():
    """
    L'immagine dell'archivio, con dentro i dieci file.

    Nessuna data di modifica viene scritta: cosi' l'immagine e' sempre
    identica a parita' di file, e chiunque puo' rifarla e ottenere lo
    stesso identico risultato. E' la stessa ragione per cui il dispositivo
    non scrive niente da solo.
    """
    try:
        from littlefs import LittleFS
    except ImportError:
        # Senza questo messaggio si vedrebbe solo un errore di Python, e chi
        # non programma non saprebbe che gli manca una libreria, ne' quale.
        print("ERRORE: manca la libreria littlefs, che serve a impacchettare")
        print("i file del programma dentro il .uf2.")
        print()
        print("Si installa nell'ambiente isolato del progetto, verificandone")
        print("l'impronta: la procedura completa e' in LEGGIMI-uf2.md, sotto")
        print("\"La libreria in piu'\".")
        print()
        print("Non serve per verificare i calcoli: test_bip39.py e")
        print("test_diceware.py girano con la sola libreria standard.")
        sys.exit(1)

    fs = LittleFS(block_size=BLOCCO,
                  block_count=ARCHIVIO_BYTE // BLOCCO,
                  prog_size=SCRITTURA,
                  read_size=LETTURA,
                  mount=False)
    fs.format()
    fs.mount()
    for nome in FILE_DISPOSITIVO:
        with open(nome, "rb") as f:
            dati = f.read()
        with fs.open(nome, "wb") as f:
            f.write(dati)
        print("   %-20s %7d byte" % (nome, len(dati)))
    fs.unmount()
    return bytes(fs.context.buffer)


# ---------------------------------------------------------------------------
# 2. il file .uf2
# ---------------------------------------------------------------------------

def leggi_uf2(percorso):
    """I blocchi del .uf2 ufficiale di MicroPython: (indirizzo, dati, famiglia)."""
    with open(percorso, "rb") as f:
        dati = f.read()
    if len(dati) % 512:
        sys.exit("ERRORE: %s non e' un .uf2 valido." % percorso)
    fuori = []
    for i in range(len(dati) // 512):
        b = dati[i * 512:(i + 1) * 512]
        m0, m1, bandiere, indirizzo, quanti = struct.unpack("<5I", b[:20])
        famiglia = struct.unpack("<I", b[28:32])[0]
        if m0 != UF2_MAGIC0 or m1 != UF2_MAGIC1:
            continue
        # Le bandiere vanno CONSERVATE, non ricostruite. Il primo blocco dei
        # .uf2 per RP2350 ha anche il bit 0x8000 ("qui dentro ci sono tag di
        # estensione"): riscrivendolo come un blocco qualunque si perde, e il
        # caricatore del Pico non riconosce piu' l'immagine e non riavvia.
        numero, totale = struct.unpack("<2I", b[20:28])
        fuori.append((indirizzo, b[32:32 + quanti], famiglia, bandiere,
                      numero, totale))
    return fuori


def scrivi_uf2(blocchi, percorso):
    """
    Scrive i blocchi rinumerandoli tutti.

    ATTENZIONE, E' IL PUNTO DELICATO: ogni blocco .uf2 porta scritto il
    proprio numero e QUANTI sono in tutto. Accodando semplicemente due file
    uno all'altro, i blocchi di MicroPython continuerebbero a dichiarare il
    totale vecchio, e il caricatore del Pico crederebbe di aver finito a
    meta' strada.

    MA LA NUMERAZIONE NON E' UNICA: il caricatore tiene un conto separato
    per ogni "famiglia" di blocchi. Il .uf2 di MicroPython per RP2350 ne ha
    due: un blocco solo di famiglia ABSOLUTE (che dichiara un totale di 2, e
    resta apposta incompleto) e 1282 blocchi della famiglia del chip. Se si
    rinumera tutto in un'unica sequenza, come si faceva prima, la famiglia
    del chip non riceve mai il suo blocco numero 0 e quella ABSOLUTE aspetta
    blocchi che non arriveranno: nessuna delle due si completa e il
    dispositivo NON si riavvia mai. Provato sull'hardware il 27/08/2026.

    Quindi: le famiglie a cui aggiungiamo blocchi si rinumerano daccapo,
    quelle che restano come sono non si toccano.
    """
    nuove = {b[2] for b in blocchi if b[4] is None}
    quanti_per_famiglia = {}
    for b in blocchi:
        quanti_per_famiglia[b[2]] = quanti_per_famiglia.get(b[2], 0) + 1
    contatore = {}
    with open(percorso, "wb") as f:
        for indirizzo, dati, famiglia, bandiere, numero, totale in blocchi:
            if famiglia in nuove:
                numero = contatore.get(famiglia, 0)
                contatore[famiglia] = numero + 1
                totale = quanti_per_famiglia[famiglia]
            intestazione = struct.pack(
                "<8I", UF2_MAGIC0, UF2_MAGIC1, bandiere,
                indirizzo, len(dati), numero, totale, famiglia)
            f.write(intestazione + dati.ljust(476, b"\x00")
                    + struct.pack("<I", UF2_MAGIC_FINE))
    return len(blocchi)


def blocchi_da(immagine, indirizzo_base, famiglia):
    """
    Spezza l'immagine dell'archivio in blocchi da 256 byte, SALTANDO quelli
    ancora vergini (tutti 0xFF, cioe' memoria mai scritta).

    Si puo' saltare perche' ogni blocco .uf2 si porta dietro il proprio
    indirizzo: non devono essere uno di fila all'altro. E conviene, perche'
    littlefs sparge i file in giro per l'archivio invece di metterli tutti
    all'inizio - lo fa apposta, per non consumare sempre le stesse celle di
    memoria. Scrivendo tutto il tratto dal primo all'ultimo blocco usato ci
    porteremmo dietro 2,4 MB di vuoto: cosi' invece si scrivono solo i
    224 KB che contengono davvero qualcosa.

    E' sicuro anche rispetto a un'installazione precedente, per due motivi.
    Il caricatore del Pico cancella l'intero settore da 4096 byte prima di
    scriverne anche un solo pezzo, quindi i settori toccati restano puliti.
    E l'elenco dei file, che sta nei primi due blocchi, viene riscritto per
    intero: qualunque file di prima diventa irraggiungibile, e lo spazio che
    occupava risulta libero.
    """
    fuori = []
    for scarto in range(0, len(immagine), CARICO):
        pezzo = immagine[scarto:scarto + CARICO]
        if pezzo == b"\xff" * CARICO:
            continue
        fuori.append((indirizzo_base + scarto, pezzo, famiglia,
                      UF2_FLAG_FAMIGLIA, None, None))
    return fuori


def main():
    import prepara_impronta as imp

    print("=" * 62)
    print("  UN SOLO FILE DA TRASCINARE")
    print("=" * 62)

    uf2_micropython = imp.verifica_uf2(imp.trova_uf2())
    print("\nMicroPython : %s" % uf2_micropython)

    mancanti = [f for f in FILE_DISPOSITIVO if not os.path.exists(f)]
    if mancanti:
        sys.exit("ERRORE: mancano dei file: %s" % ", ".join(mancanti))

    print("\nCostruisco l'archivio con dentro il programma:")
    immagine = costruisci_archivio()

    blocchi_firmware = leggi_uf2(uf2_micropython)
    famiglia = next(b[2] for b in blocchi_firmware
                    if b[2] == imp.FAMIGLIA_RP2350)
    blocchi_archivio = blocchi_da(immagine, INIZIO_FLASH + ARCHIVIO_INIZIO,
                                  famiglia)

    uscita = "prisma-%s.uf2" % VERSIONE
    totale = scrivi_uf2(blocchi_firmware + blocchi_archivio, uscita)

    peso = os.path.getsize(uscita)
    with open(uscita, "rb") as f:
        impronta_file = hashlib.sha256(f.read()).hexdigest()

    print("\nfirmware    : %d blocchi (MicroPython, non toccato)"
          % len(blocchi_firmware))
    print("archivio    : %d blocchi (%d KB dei %d KB disponibili)"
          % (len(blocchi_archivio), len(blocchi_archivio) * CARICO // 1024,
             ARCHIVIO_BYTE // 1024))
    print("\nGENERATO: %s  (%d KB, %d blocchi in tutto)"
          % (uscita, peso // 1024, totale))
    print("SHA-256 : %s" % impronta_file)
    print("\nSi carica cosi': tieni premuto BOOTSEL mentre colleghi il cavo,")
    print("compare un disco, ci trascini sopra questo file. Basta.")

    # ------------------------------------------------------------------
    # IL PROMEMORIA NOSTR.
    #
    # Sul foglio stampato c'e' scritto di confrontare le tre parole con
    # quelle pubblicate su Nostr. Se la nota non viene pubblicata, quella
    # riga manda il lettore nel vuoto - ed e' peggio che non averla
    # scritta, perche' insegna a ignorare le verifiche. Le parole cambiano
    # a ogni riga toccata nel firmware, quindi la nota va rifatta a ogni
    # release: qui sotto esce gia' pronta da copiare.
    # le stesse tre parole che calcola prepara_impronta.py, dalla stessa
    # funzione: non ricalcolate qui, per non rischiare che divergano
    parole = "  ".join(w.upper() for w in imp.calcola_parole(uf2_micropython)[1])
    print("\n" + "=" * 62)
    print("  DA PUBBLICARE SU NOSTR, PRIMA DI STAMPARE IL FOGLIO")
    print("=" * 62)
    print("""
PRISMA \u2014 il calcolatore offline

IMPRONTA DEL FIRMWARE %s

All'accensione il dispositivo deve mostrare esattamente queste
tre parole:

%s

Se ne mostra tre diverse, dentro c'\u00e8 qualcosa di diverso:
fermati e riscrivi il firmware.

Questa nota \u00e8 la fonte con cui confrontarle: sul foglio dentro
la scatola c'\u00e8 scritto di verificarle qui.

File da caricare: prisma-%s.uf2
SHA-256:
%s

Codice, file e guida:
https://github.com/Finalstepbitcoin/prisma/releases/tag/v%s

#bitcoin #nostr
""" % (VERSIONE, parole, VERSIONE, impronta_file, VERSIONE))
    print("=" * 62)


if __name__ == "__main__":
    main()

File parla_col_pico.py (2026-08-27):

#!/usr/bin/env python3
"""
parla_col_pico.py  --  Final Step Bitcoin / Prisma

Piccolo strumento per parlare con il Pico senza installare NIENTE.
Usa solo la libreria standard di Python (termios, select): niente pip,
niente programmi di terze parti.

A cosa serve:
    - eseguire un comando sulla scheda e vederne il risultato
    - copiare un file dal Mac alla scheda

Uso:
    python3 parla_col_pico.py info
    python3 parla_col_pico.py esegui "print(1+1)"
    python3 parla_col_pico.py copia bip39_checksum.py
    python3 parla_col_pico.py verifica bip39_checksum.py
    python3 parla_col_pico.py elenco

    python3 parla_col_pico.py prepara bip39_checksum.py    (copia SENZA attivare)
    python3 parla_col_pico.py attiva bip39_checksum.py main.py ...   (attiva in blocco)
    Usati da installa.py per installare piu' file con un'unica finestra
    di rischio breve invece che una per file: vedi comando_prepara e
    comando_attiva qui sotto.

Come funziona: MicroPython espone una "REPL grezza" (raw REPL), un canale
pensato apposta per essere pilotato da un programma invece che da una persona.
Si entra con CTRL-A, si manda il codice, si esegue con CTRL-D.
"""

import glob
import hashlib
import os
import select
import sys
import termios
import time

CTRL_A = b"\x01"   # entra in REPL grezza
CTRL_B = b"\x02"   # torna alla REPL normale
CTRL_C = b"\x03"   # interrompi il programma in corso
CTRL_D = b"\x04"   # esegui


def trova_porta():
    porte = sorted(glob.glob("/dev/cu.usbmodem*"))
    if not porte:
        print("ERRORE: nessuna scheda collegata.")
        print("Controlla il cavo, e che sia un cavo DATI e non solo da ricarica.")
        sys.exit(1)
    return porte[0]


class Pico:
    def __init__(self, porta=None):
        self.porta = porta or trova_porta()
        self.fd = os.open(self.porta, os.O_RDWR | os.O_NOCTTY | os.O_NONBLOCK)
        self._modo_grezzo()

    def _modo_grezzo(self):
        """Toglie ogni elaborazione del testo: i byte passano come sono."""
        a = termios.tcgetattr(self.fd)
        a[0] = 0                       # iflag
        a[1] = 0                       # oflag
        a[2] = termios.CS8 | termios.CREAD | termios.CLOCAL
        a[3] = 0                       # lflag: niente eco, niente righe
        a[6][termios.VMIN] = 0
        a[6][termios.VTIME] = 0
        termios.tcsetattr(self.fd, termios.TCSANOW, a)

    def scrivi(self, dati):
        while dati:
            select.select([], [self.fd], [], 2)
            n = os.write(self.fd, dati[:256])
            dati = dati[n:]
            time.sleep(0.002)

    def leggi_fino(self, atteso, scadenza=10):
        """Legge finche' non arriva la sequenza attesa (o scade il tempo)."""
        buf = b""
        limite = time.time() + scadenza
        while time.time() < limite:
            pronti, _, _ = select.select([self.fd], [], [], 0.05)
            if pronti:
                pezzo = os.read(self.fd, 4096)
                if pezzo:
                    buf += pezzo
                    if atteso in buf:
                        return buf
        raise TimeoutError(
            "la scheda non ha risposto entro %d secondi.\n"
            "Ricevuto finora: %r" % (scadenza, buf[-200:]))

    def riavvia(self):
        """
        Riavvio "morbido": azzera la memoria di lavoro e scarica tutti i
        moduli, come se la scheda fosse appena accesa. Non tocca i file.
        Serve perche' fra un comando e l'altro la scheda NON riparte da sola:
        senza questo, le prove si portano dietro la memoria di quelle prima.
        """
        self.scrivi(CTRL_B)          # esci dalla REPL grezza
        time.sleep(0.1)
        self.scrivi(CTRL_D)          # riavvio morbido
        time.sleep(1.5)
        # svuota quello che la scheda ha stampato riavviandosi
        while True:
            pronti, _, _ = select.select([self.fd], [], [], 0.3)
            if not pronti:
                break
            os.read(self.fd, 4096)
        self.entra_grezza()

    def entra_grezza(self):
        self.scrivi(CTRL_C)      # ferma qualunque cosa stia girando
        time.sleep(0.1)
        self.scrivi(CTRL_C)
        time.sleep(0.1)
        self.scrivi(CTRL_A)
        self.leggi_fino(b"raw REPL; CTRL-B to exit\r\n>")

    def esci_grezza(self):
        self.scrivi(CTRL_B)

    def esegui(self, codice, scadenza=180):
        """Esegue codice sulla scheda e restituisce (uscita, errore)."""
        self.scrivi(codice.encode("utf-8"))
        self.scrivi(CTRL_D)
        risposta = self.leggi_fino(b"\x04>", scadenza)
        if not risposta.startswith(b"OK"):
            raise RuntimeError("la scheda ha rifiutato il codice: %r" % risposta[:120])
        corpo = risposta[2:]
        pezzi = corpo.split(b"\x04")
        uscita = pezzi[0].decode("utf-8", "replace")
        errore = pezzi[1].decode("utf-8", "replace") if len(pezzi) > 1 else ""
        return uscita, errore

    def chiudi(self):
        try:
            self.esci_grezza()
        finally:
            os.close(self.fd)


def comando_esegui(pico, codice):
    uscita, errore = pico.esegui(codice)
    if uscita:
        print(uscita, end="")
    if errore.strip():
        print("\n--- ERRORE SULLA SCHEDA ---")
        print(errore.strip())
        return 1
    return 0


def comando_info(pico):
    codice = (
        "import sys, gc, os, machine\n"
        "gc.collect()\n"
        "print('MicroPython :', '.'.join(str(x) for x in sys.implementation.version))\n"
        "print('piattaforma :', sys.platform)\n"
        "print('frequenza   : %d MHz' % (machine.freq()//1000000))\n"
        "print('RAM libera  : %d KB' % (gc.mem_free()//1024))\n"
        "s = os.statvfs('/')\n"
        "print('disco libero: %d KB su %d KB' % (s[0]*s[3]//1024, s[0]*s[2]//1024))\n"
    )
    return comando_esegui(pico, codice)


def comando_elenco(pico):
    return comando_esegui(pico, "import os\nfor f in os.listdir('/'): print(f)\n")


def _cancella_su_scheda(pico, nome):
    """Best-effort: non importa se il file non c'era gia'."""
    pico.esegui("import os\ntry:\n    os.remove(%r)\nexcept OSError:\n    pass\n" % nome)
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

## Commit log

2026-08-11 Checksum Tool: dispositivo offline per BIP39 e Diceware
    Un dispositivo da circa 15 euro, senza radio, che completa un seed BIP39
    (calcolando l'ultima parola) e genera passphrase col metodo Diceware.
    Non salva nulla, non genera entropia ma la conserva, e non calcola chiavi
    private.
    Sul dispositivo (MicroPython, Raspberry Pi Pico 2):
    - calcolo del checksum BIP39, verificato contro i vettori ufficiali
    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
    [cornice.stl, custodia_completa.3mf, custodia_completa.stl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]
2026-08-21 Fix build integrity, atomic install, e chiarimento impronta (issue #1, #2, #4)
    Risponde a tre issue di security review aperte da bitwalt:
    - #1: pin dell'hash atteso per dizionario BIP39, liste Diceware e file .uf2
    di MicroPython. Gli script si fermano se la fonte scaricata non
    corrisponde al valore verificato, invece di generare firmware da un
    contenuto diverso da quello atteso.
    - #2: il README e impronta.py dicevano che l'impronta di avvio protegge da
    manomissioni "avvenute dopo la consegna". Non e' vero: chi manomette il
    firmware in qualunque fase controlla anche il codice che calcola e mostra
    quel valore. Riscritto per dire chiaramente che protegge solo da
    corruzione accide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
    [impronta.py, installa.py, parla_col_pico.py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]
2026-08-21 Usa uno spazio come separatore reale nella passphrase Diceware (issue #3)
    Le voci Diceware hanno lunghezza variabile e alcune sono l'inizio di
    altre (es. "a" e "aa" nella lista inglese): senza un separatore nella
    stringa digitata, tiri di dadi diversi potevano produrre la stessa
    identica passphrase (es. [a, aa] e [aa, a] diventavano entrambi "aaa").
    Non un dettaglio di formato: una vera collisione che riduceva l'entropia
    reale sotto quella dichiarata a schermo.
    mostra_unita() ora unisce le parole con " ".join invece di "".join: lo
    spazio e' parte della passphrase da digitare, non solo dell'elenco
    numerato. Aggiornati anche il testo a schermo e l'avviso che precede la
    schermata, per rendere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
    [interfaccia.py]
2026-08-21 Alza il massimo Diceware a 20 parole, in due schermate da 10
    MASSIMO_PAROLE era 10, legato allo spazio disponibile sullo schermo
    dell'elenco numerato (mostra_passphrase) e alle dieci righe della scheda
    di carta. Il calcolo dei bit non aveva bisogno di modifiche (la formula
    di riserva oltre le 10 parole c'era gia'): estesa comunque a mano la
    tabella BIT_DECIMI fino a 20, con lo stesso criterio gia' usato per 1-10,
    per non introdurre un arrotondamento calcolato dal vivo su MicroPython
    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
2026-08-21 Aggiunge la guida in un foglio (fronte/retro) per la scatola
    Foglio A4 stampabile, generato da guida/sorgente.html via guida/build.sh:
    sette sezioni, dalla prima accensione (impronta del firmware) all'uso
    delle due modalita' fino alle avvertenze. Aggiornata per riflettere le
    correzioni delle issue #1-#4 (testo sull'impronta, spazio nella
    passphrase, nuovo massimo di 20 parole Diceware in due schermate).
    Non ancora messa online sul sito.
2026-08-21 Correzioni dalla revisione di sicurezza: installazione, Diceware, impronta
    INSTALLAZIONE (il problema piu' serio trovato): parla_col_pico.py e
    installa.py sostituivano un file alla volta con copia+verifica+scambio,
    quindi un cavo staccato a meta' installazione lasciava il dispositivo con
    una mescolanza di file vecchi e nuovi. Ora installa.py prepara e verifica
    TUTTI i file sotto nome temporaneo prima di toccare qualunque file attivo
    (comando_prepara), poi li attiva tutti insieme in un solo comando
    (comando_attiva): l'attivazione e' un'operazione di filesystem, non un
    trasferimento dati, quindi la finestra di rischio scende da minuti a
    millisecondi. In piu' lo scambio prova prima un rename di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
    [installa.py, interfaccia.py, parla_col_pico.py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]
2026-08-21 Precisa il commento sulla tabella dei bit e avvisa in guida della seconda pagina
    diceware.py: il commento su BIT_DECIMI diceva che l'intera tabella
    corrisponde ai valori stampati sulla scheda di carta. Non e' piu' vero
    da quando il massimo e' salito a 20: solo le prime 11 voci (0-10 parole)
    sono davvero sulla scheda, che resta a dieci righe. Precisato, e spiegato
    dove si legge il totale dei bit oltre le dieci parole (solo a schermo).
    guida/sorgente.html: aggiunto un promemoria nel passo in cui si ricopiano
    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
2026-08-21 Il banner 'Scheda su ...' va su stderr, non su stdout
    parla_col_pico.py stampava "Scheda su /dev/cu.usbmodemXXXX" su stdout
    prima di eseguire qualunque comando. elenco_dispositivo() in installa.py
    prende ogni riga non vuota dell'output come nome di file: quel banner ci
    finiva dentro anche lui. Innocuo per fortuna (non finisce ne' per .py ne'
    per .tmp, quindi non fa scattare i controlli sui file estranei), ma
    fragile - e sporcava anche la riga di stato dopo 'attiva'.
    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
2026-08-21 Aggiunge B) canc alla conferma di ogni parola Diceware (issue #3 audit)
    Prima, l'unico modo di correggere l'ultima parola tirata era premere A
    (continua) e poi B nella schermata dei dadi successiva - un giro in piu'
    non necessario. E al massimo di parole quel giro non era nemmeno
    disponibile, perche' "A" chiudeva subito la sessione: non c'era modo di
    ritirare l'ultima parola se ci si accorgeva subito di un errore.
    Ora "B) canc" e' un'opzione diretta sulla stessa schermata di conferma,
    sia sotto sia al massimo: toglie l'ultima parola e la richiede da capo,
    stessa schermata dei dadi di sempre.
    Verificato con una simulazione della macchina a stati (stessa logica,
    senza la parte grafica) su 5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
    [interfaccia.py]
2026-08-21 Copertura per B) canc e la doppia schermata Diceware (issue #4 audit)
    Aggiunge due prove alla modalita' dadi:
    - dadi_annulla: tira 3 parole, alla terza usa B) canc per ritirarla e
    ridarla, poi si ferma con l'avviso sotto le 6 - copre il pulsante
    aggiunto nel commit precedente, mai esercitato da un test finora.
    - dadi_due_schermate: 12 parole, naviga davvero alla seconda pagina
    dell'elenco numerato con la freccia (non si limita a premere subito
    A), copre mostra_passphrase oltre le 10 parole - anche questo mai
    testato finora.
    Nel controllare i conti per la seconda prova ho trovato che le prove
    Diceware GIA' ESISTENTI (dadi, dadi_avviso) erano rotte da quando ho
    aggiunto la schermata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
    [prova_percorsi.py]
2026-08-21 Aggiorna i conteggi dei test nel README (30->32, 15->17)
    Rimasti indietro rispetto al codice: test_diceware.py fa 32 controlli
    da quando verifica l'impronta pinnata (issue #1), non piu' 30; e
    prova_percorsi.py esegue 17 percorsi da quando ci sono anche B) canc e
    la doppia schermata, non piu' 15. Verificati entrambi rieseguendo
    davvero gli script (32 confermato da test_diceware.py) e contando
    programmaticamente le chiamate a prova() invece che a mano (17
    confermato, tenendo conto che il percorso della lista Diceware gira
    due volte, inglese e italiano).
2026-08-22 Revisione delle parole del seed prima del calcolo del checksum
    Fra l'inserimento delle 11/23 parole e il calcolo del checksum non
    c'era nessun modo di controllare di aver scelto le parole giuste
    dall'autocompletamento: qualunque parola del dizionario BIP39 produce
    comunque 128 (o 8) candidate valide, quindi un errore di selezione non
    genera nessun avviso - il seed completato sarebbe semplicemente diverso
    da quello vero, senza che nessuno se ne accorga.
    Aggiunta rivedi_parole(): l'elenco numerato delle parole appena
    inserite, su piu' pagine da dieci se servono (fino a tre, per un seed
    da 24). "A) avanti" per procedere, "B) rifai" per rifare da capo tutto
    l'inserimento - non si corregge una p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
    [interfaccia.py, prova_percorsi.py]
2026-08-24 Rename the project from Checksum Tool to Sintesi
    The device now has a proper name. "Checksum Tool" was a working title that
    described the function; "Sintesi" (Italian for synthesis) names what the
    device does conceptually — many inputs (eleven words, seven bits, five
    dice) converge into one result. It is also the optical opposite of a
    prism, which was the first candidate: a prism splits, this recombines.
    Renamed everywhere: source file headers, README, the welcome and info
    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
2026-08-24 Move the paper cards out to their own repository
    The BIP39 and Diceware paper cards are printable tools that stand on their
    own: you can use them without ever touching the device, and you can use the
    device with a card you made yourself. Keeping them inside the firmware
    repository suggested a dependency that does not exist.
    They now live in Finalstepbitcoin/schede-carta, linked from the README. The
    uncommitted improvement to the BIP39 card (marking which bits of the last
    word are entropy and which are checksum) moved with them and is the first
    commit there.
    One loose end worth writing down: the Diceware card prints an entropy table
    (12.9 / 25.8 / ... / 129.2 bits) whose values also exist,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
2026-08-24 Keep the brand assets out of the repository
    marchio/ holds the SINTESI lettering and the channel logo: material for
    printing the guide and the packaging, not for building or verifying the
    device. I added it two commits ago arguing that without it nobody could
    regenerate the logo — that argument was weak. The guide embeds the logo as
    base64 and is self-contained, so nothing here depends on those files.
    There is also a mild reason against publishing them: print-ready originals
    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
2026-08-25 Title the project "Sintesi - calcolatore offline"
    The README opened with "Sintesi - Final Step Bitcoin", which named the
    channel rather than the thing. The device is a calculator: it works out the
    last word of a seed and turns dice into Diceware words, and it does so with
    nothing connected. The channel is still credited two lines below.
    The repository description on GitHub was updated separately: it still
    advertised the device at 15 euro, while the README already said 20.
2026-08-25 Trim the guide's README down to what a reader needs
    guida/LEGGIMI.md had grown into a printing manual: how to rebuild the PDF,
    the two-page constraint and how to claw back millimetres, the QR
    regeneration procedure, where the two logos come from. None of that helps
    someone who lands on the repository wanting to rebuild the device — it is
    production detail for whoever prints the sheet.
    Those sections now live outside the repository, in guida/NOTE-DI-STAMPA.md,
    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
2026-08-25 Ship the printable guide as a PDF, and say whose firmware its words describe
    guida/ now carries the finished sheet, not just its source: anyone can
    download and print the same A4 that goes in the box, without buying an
    assembled device. build.sh writes both copies, the one for the website and
    the one in the repository, because leaving the second to be copied by hand
    would eventually mean reprinting the sheet and forgetting GitHub — and then
    the downloadable PDF would advertise fingerprint words that no longer match
    the firmware being shipped.
    The README now spells out what those three words mean and, more importantly,
    what they do not mean. They are the fingerprint of the firmware I flash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
2026-08-25 Cut the guide's README back to the two things a reader needs
    Removed "DA AGGIORNARE A OGNI VERSIONE DEL FIRMWARE" and "Cosa dice la
    guida, e perché". Both were notes to myself about producing and editing the
    sheet — when to recalculate the fingerprint before a reprint, why certain
    warnings must never be cut for space, and the layout trap where longer
    fingerprint words pushed the front page onto a third sheet. Useful, but not
    to someone who came here to build the device. They moved to
    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
2026-08-25 Archive the original word lists, and stop executing generated files
    Two changes to the build scripts, both about not depending on someone
    else's server and not running code we did not write.
    The Diceware lists now have an archived copy in liste-originali/, exactly
    as their authors publish them, with the full text of the GPL and a LEGGIMI
    recording author, licence, address, version and SHA-256 of each. The
    generator still downloads from the original source every time and falls
    back to the local copy only when the download fails; in both cases it
    compares the SHA-256 against the value pinned in the code, so the archived
    copy is a safety net and not a shortcut. Verified: with the network
    unava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
    [prepara_diceware.py, prepara_wordlist.py]
2026-08-25 Refuse to print the guide when its three words are stale
    The sheet in the box carries the three words the device must show at power
    on. Change any file of the firmware and those words change with it, so a
    guide printed from an older state makes a healthy device look tampered
    with. That is the worst failure this feature can have: it teaches the buyer
    that a mismatch is normal, which is precisely the signal we asked them to
    act on.
    build.sh already refused to let the sheet grow past two sides. It now also
    computes the firmware fingerprint and compares it with the words in
    sorgente.html, stopping before it touches the PDF if the two disagree.
    Tested both ways: matching words print, stale words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
2026-08-25 Add the video-guide QR to the sheet, and refresh the printed words
    The guide gains a second QR code, in the bottom corner opposite the channel
    signature, pointing at the video guide. Its address is still a placeholder
    that leads to the channel, so that anyone scanning an early sheet lands
    somewhere real instead of on an error; it has to be replaced with the
    direct link before the sheet is printed.
    The generator now holds both codes in one list, each with the style class
    it carries into the SVG, so a regenerated code can be pasted over the old
    one without any chance of swapping the two.
    The printed fingerprint moves to BLAST SAIL SPOIL, which is what the
    firmware shows now that impronta.py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
2026-08-25 Say in the README what the fingerprint covers and where the lists live
    Two claims had stopped being true. The fingerprint section described the
    hash as covering "the contents of every file of the program", which now
    means every file on the device, of any extension, subdirectories included -
    and the reason is worth stating, because MicroPython loading .mpy modules
    from /lib is exactly the gap the old wording left open.
    And the licence section still announced that the word lists are not in this
    repository. The two Diceware lists now are, archived as their authors
    publish them, used only when the download fails and always checked against
    the pinned hash.
    Also added impronta.py to the table of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
2026-08-25 Keep the security review reports off the repository
    They are working documents, written for whoever builds the device: internal
    decisions, accepted risks, things still to do. One of them describes the
    repository while it was still private, which stops making sense the moment
    it is not. Publishing a review is a fine thing to do, but it means rewriting
    it for an outside reader, not dropping the working copy in here by mistake.
    Same reasoning already applied to guida/NOTE-DI-STAMPA.md: they stay on the
    disk, next to the code, just not in the repository.
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2026-08-27 Point the printed QR at the renamed repository
    The QR on page two still encoded github.com/Finalstepbitcoin/sintesi while
    the line of text beside it already read prisma: the image is generated
    once and pasted into the source, so renaming the address in
    prepara_qr_guida.py was not enough on its own.
    Regenerated and pasted. The code is smaller than before, 29 modules
    against 33, because the new address is shorter, so the whole svg block was
    replaced rather than just its dots. Decoded from the built PDF it now
    returns the prisma address.
2026-08-27 Point the printed QR at the renamed repository
    Same fix as on main: the code still encoded the sintesi address while the
    text beside it read prisma. The svg block is replaced whole, since the
    shorter address produces a smaller code, 29 modules against 33.
    Note for next time: .venv-strumenti lives only in the main worktree, so
    prepara_qr_guida.py cannot run from here. The generated svg was copied
    across rather than regenerated.
2026-08-27 Use the mirrored lettering on the printed guide
    The masthead now carries PRISMA-riflesso, the mark with its mirrored
    reflection underneath, the same one the video cover uses.
    The h1 below it moves from -1.5mm to +1.2mm. It was pulled up to sit tight
    against the old mark, which had nothing under it; the reflection was
    landing on the G of GUIDA. The sheet still prints as two sides, which is
    the constraint that matters.
    The mark itself is unchanged in size: both files share the same 870x456
    canvas with the letters in the same place, so the 54mm width and the
    -2.3mm inset still hold.
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2026-08-27 Number the uf2 blocks per family, not across the whole file
    The single .uf2 built here never booted on real hardware: the file copied
    across, the bootloader accepted every block, and the device just sat in
    BOOTSEL without rebooting. First hardware run of this branch, 27/08/2026.
    Block numbering is tracked per family, not per file, and the MicroPython
    image for RP2350 carries two: one ABSOLUTE block that declares a total of
    2 and stays deliberately incomplete, and 1282 blocks of the chip family.
    Renumbering everything into a single 0..2076 run meant the chip family
    never received its block 0 (that number went to the ABSOLUTE block) and
    the ABSOLUTE family waited for blocks that never came. N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
    [crea_uf2.py, prova_uf2.py]
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2026-08-27 Make the one-file install the documented way
    The README still walked through loading MicroPython and then copying ten
    files over a terminal, and never mentioned crea_uf2.py, which had just
    arrived on main. Anyone reading the project would have followed the long
    road without knowing the short one existed.
    The build section now ends with the packaged file, and a new section says
    what to do with it: hold BOOTSEL, drag, done. It also records what cost us
    an afternoon, that on macOS the file has to be dragged from the Finder
    rather than copied from a terminal, where cp reports success and the
    device silently stays in BOOTSEL.
    installa.py keeps its place, demoted to what it is now: the long road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
2026-08-27 Clean up what a public repository would expose
    Audit before making the repository public. One real problem and four
    inconsistencies.
    guida/build.sh hardcoded an absolute path on the author's Mac, which would
    have published a username and a folder layout, and would have failed on
    anyone else's machine since the script runs under set -e. The PDF is now
    written inside the repository, the only place that exists everywhere, and
    an optional extra copy is read from guida/copia-locale.txt, which is
    ignored: a personal detail of one computer, not part of the project.
    The rest were documents drifting from the code: LEGGIMI-uf2.md still
    promised 11 checks where prova_uf2.py now runs 12, liste-origina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
    [crea_uf2.py]
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2026-08-27 Fix what a second read of the documents turned up
    LEGGIMI-uf2.md still ended with a section headed "DA FARE: la prova
    sull'hardware", telling the reader the test was pending, expecting a
    fingerprint two revisions old, and closing with "the branch must not be
    merged into main until this is done" — inside main, after the merge. It now
    records what the hardware run actually found: the file was rejected, the
    block numbering was counted per file instead of per family, and two of the
    checks were asserting the wrong rule.
    The instructions for installing littlefs-python are for an Apple-silicon
    Mac; on anything else both the filename and the hash differ, which the page
    now says.
    The README opene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
2026-08-27 Say which library is missing, instead of a stack trace
    Cloning the repository the way a stranger would and following the README,
    the build stops on a raw ImportError. Someone who does not write Python has
    no way to know that a library is missing, let alone which one, while the
    same script prints a clear line when MicroPython is absent.
    It now says what is missing, points at the section that installs it with
    its hash, and adds that the checks on the calculations do not need it.
    [crea_uf2.py]
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2026-08-27 Hold the case design back until it is right
    The case folder carried six files of work in progress: shells, buttons, a
    joystick, a paper test, measurements still being corrected. Published as
    they are, someone would spend an afternoon and a spool of filament
    printing a part that does not fit.
    Everything is untracked rather than deleted: the files stay on the author's
    disk and the folder is ignored from here on, so the next round of prints
    cannot slip into the repository by accident. What remains is a single page
    saying the design is not published yet, which is where the link will go.
    [cornice.stl, custodia_completa.3mf, custodia_completa.stl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]
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2026-08-27 Remind to publish the fingerprint on Nostr at every release
    The printed sheet tells the reader to compare the three words against the
    ones published on Nostr. If that note is never posted, the line sends
    people nowhere, which is worse than not printing it: it teaches them to
    skip verifications.
    The words change with every line touched in the firmware, so the note has
    to be reposted at every release. crea_uf2.py now prints it ready to copy,
    filled in with the version, the words and the hash of the file it just
    built, so the three can never disagree. build.sh prints a shorter reminder
    when it regenerates the sheet.
    The words come from prepara_impronta.calcola_parole, the same function the
    re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
    [crea_uf2.py]
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2026-09-01 Point the second QR at the video guide
    It was a placeholder aimed at the channel, to be replaced before printing.
    The video link is shorter than the channel one, so the code drops from 33
    to 29 modules: the whole SVG block has to be swapped, not just the address
    in the generator.
    That video must never be deleted and re-uploaded. YouTube would assign a
    new id and every sheet already printed would lead nowhere; visibility
    changes, private to scheduled to public, leave the id alone.
